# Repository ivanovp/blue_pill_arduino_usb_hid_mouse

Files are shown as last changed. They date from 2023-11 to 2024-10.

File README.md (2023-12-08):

# blue_pill_arduino_usb_hid_keyboard
Macro keyboard which uses Blue Pill (STM32F103) development board and Arduino framework.
Pressing a key sends Alt-Windows-F1 (or any combination you want) through USB to the host. The software is very simple: 
to change the key, you need to compile and re-program the device.
There is 3D printed case and 3D printed keycaps for the keyboard, but you can create your own case of course.

Schematic:
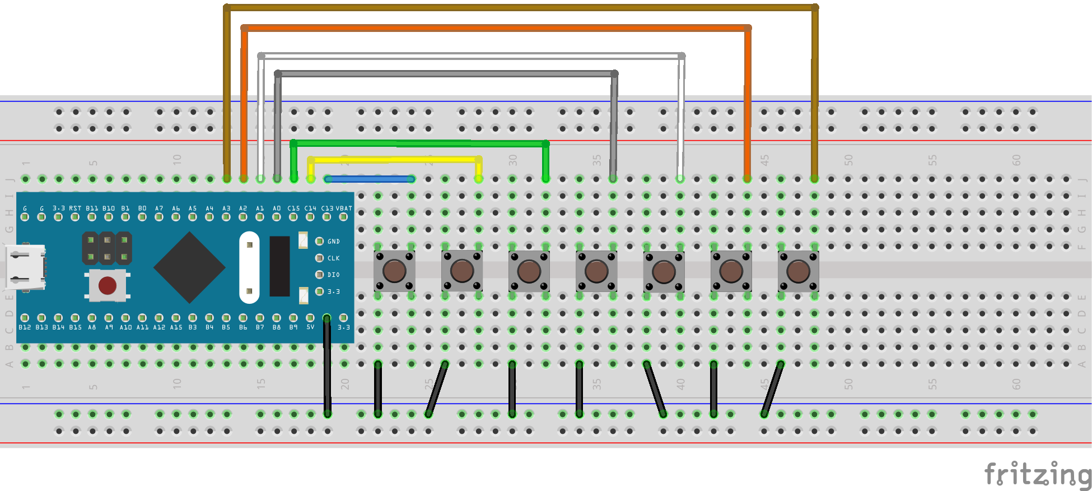
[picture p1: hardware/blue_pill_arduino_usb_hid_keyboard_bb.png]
Schematic


Photos:
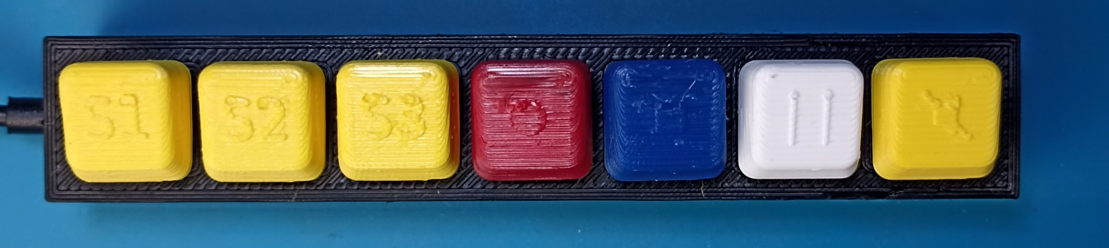
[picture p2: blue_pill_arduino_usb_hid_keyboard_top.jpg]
Macro keyboard top

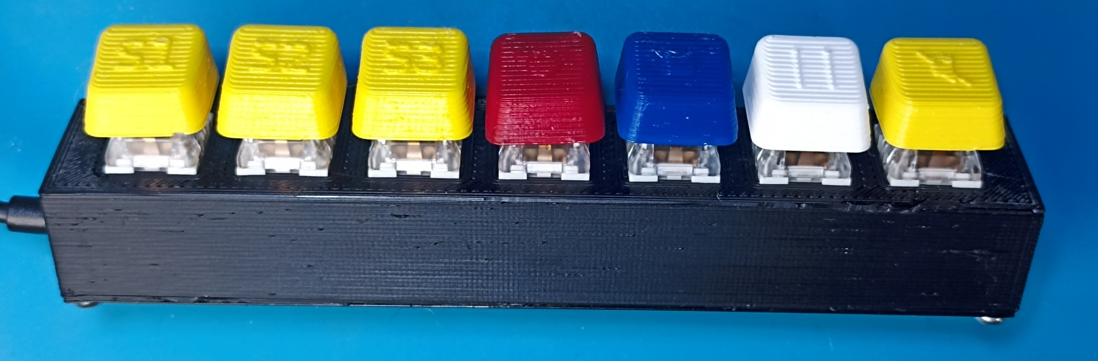
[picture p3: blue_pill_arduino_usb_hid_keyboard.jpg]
Macro keyboard


Bill of Materials:

Blue Pill (STM32F103C8, 64KiB flash):
https://www.hestore.hu/prod_10043289.html

Blue Pill (STM32F103C6, 32KiB flash):
https://pepita.hu/muszaki-cikk-elektronika-outlet-c6343/stm32f103c6t6-mikrokontroller-fejleszto-modul-p10464316

ST-Link V2:
https://www.hestore.hu/prod_10037590.html

Mechanical switches:
https://www.alza.hu/keychron-kailh-switch-set-35pcsset-brown-d6587566.htm
https://www.alza.hu/keychron-kailh-switch-set-35pcsset-red-d6587574.htm

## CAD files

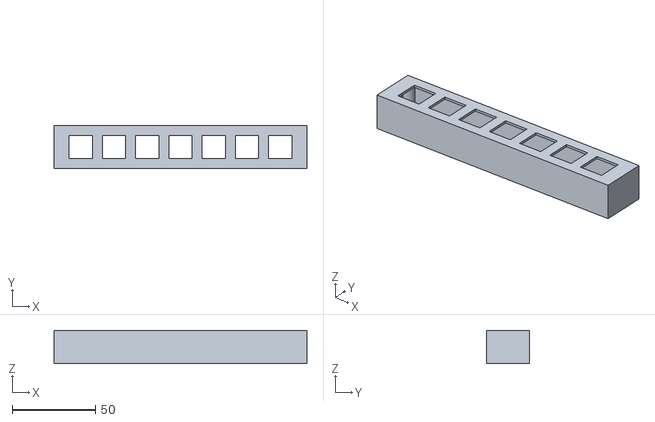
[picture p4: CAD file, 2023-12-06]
3d_printed/case/macro_keyboard_case_top.stl
152.0 x 26.0 x 20.0

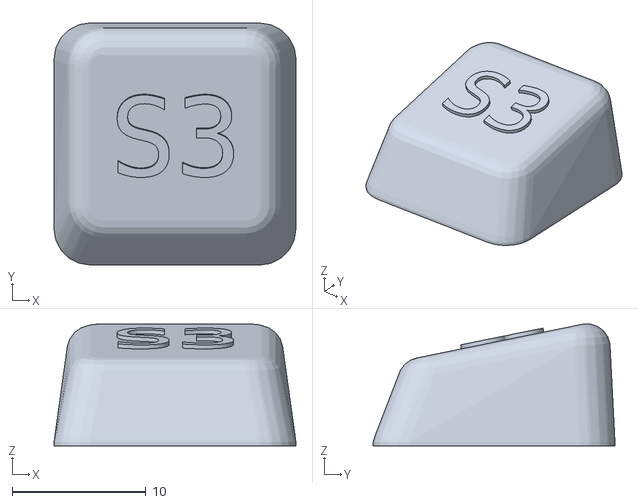
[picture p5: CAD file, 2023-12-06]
3d_printed/keycap_2783650/key_s3.stl
18.1 x 18.1 x 9.12

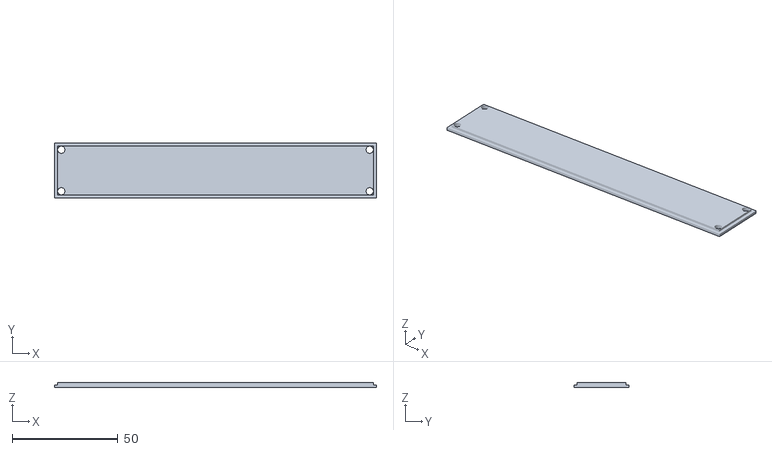
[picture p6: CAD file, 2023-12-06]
3d_printed/case/macro_keyboard_case_bottom.stl
152.0 x 26.0 x 2.40

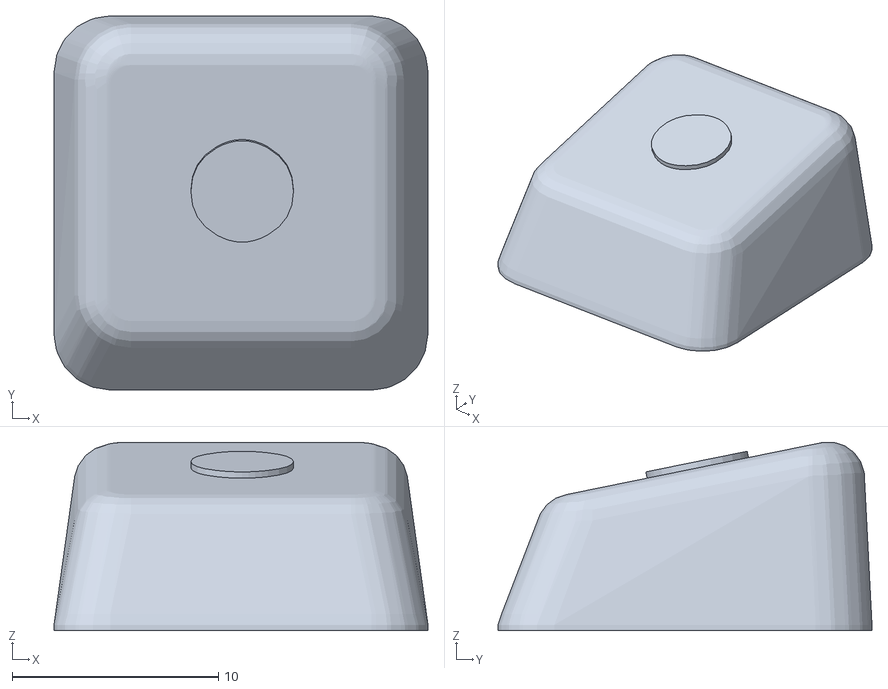
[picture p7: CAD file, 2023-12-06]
3d_printed/keycap_2783650/key_record.stl
18.1 x 18.1 x 9.12

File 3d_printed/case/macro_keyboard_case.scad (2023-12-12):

// Copyright (C) Peter Ivanov <ivanovp@gmail.com>, 2023
// License: Attribution-NonCommercial-ShareAlike (CC BY-NC-SA)

/* 1: Render top of case */
enable_top = 1;
/* 1: Render bottom of case */
enable_bottom = 0;

case_height = 20;
keybody_width = 14;
keybody_length = 14;
keybody_height = 8;
thickness = 1.3;
/* Number of keys in a row */
key_num_per_row = 7;
/* Number of rows */
key_rows = 2;
key_space_x = 6;
key_space_x_left = 3;
key_space_x_right = 3;
key_space_y = 6;
cylinder_outer_diameter = 6.4;
cylinder_inner_diameter = 2.9;
/* 4 drill's diameter to fasten bottom part to the top */
drill_diameter = 3.4;
/* Cutout for USB cable */
cutout_width = 11;
cutout_height = 8;

/* Internal variables */
delta = 0.1;
w = keybody_width + key_space_x;
fw = w * key_num_per_row + key_space_x + key_space_x_left + key_space_x_right;
d = keybody_length * key_rows + key_space_y * (key_rows + 1);
echo("Internal depth: ", d - thickness * 2);
epsilon = 0.1;
$fn = 64;

module cyl()
{
    color("lightblue") difference()
    {
        cylinder(h=case_height - thickness, d=cylinder_outer_diameter);
        translate([0, 0, -epsilon]) cylinder(h=case_height - thickness + epsilon * 2, d=cylinder_inner_diameter);
    }
}

module cyl2()
{
    translate([0, 0, -epsilon]) cylinder(h=case_height - thickness + epsilon * 2, d=drill_diameter);
}

if (enable_top)
{
    translate([cylinder_outer_diameter / 2, cylinder_outer_diameter / 2, thickness]) cyl();
    translate([fw - cylinder_outer_diameter / 2, cylinder_outer_diameter / 2, thickness]) cyl();
    translate([cylinder_outer_diameter / 2, d - cylinder_outer_diameter / 2, thickness]) cyl();
    translate([fw - cylinder_outer_diameter / 2, d - cylinder_outer_diameter / 2, thickness]) cyl();

    color("lightblue") difference()
    {
        cube([fw, d, case_height]);
        translate([thickness, thickness, -epsilon]) cube([fw - thickness * 2, d - thickness * 2, case_height - thickness + epsilon]);
        for (j = [0 : key_rows - 1])
        {
            for (i = [0 : key_num_per_row - 1])
            {
                translate([key_space_x_left + i * w + key_space_x, key_space_y + j * (keybody_length + key_space_y), case_height - keybody_height / 2]) cube([keybody_width, keybody_length, keybody_height]);
            }
        }
        translate([-epsilon, keybody_length / 2 + key_space_y - cutout_width / 2, thickness]) cube([thickness + epsilon * 2, cutout_width, cutout_height]);
    }
}

if (enable_bottom)
{
    translate([0, 0, -thickness]) difference()
    {
        union()
        {
            cube([fw, d, thickness]);
            translate([thickness + delta, thickness + delta, thickness]) cube([fw - thickness * 2 - delta * 2, d - thickness * 2 - delta * 2, thickness - delta * 2]);    
        }
        translate([cylinder_outer_diameter / 2, cylinder_outer_diameter / 2, 0]) cyl2();
        translate([fw - cylinder_outer_diameter / 2, cylinder_outer_diameter / 2, 0]) cyl2();
        translate([cylinder_outer_diameter / 2, d - cylinder_outer_diameter / 2, 0]) cyl2();
        translate([fw - cylinder_outer_diameter / 2, d - cylinder_outer_diameter / 2, 0]) cyl2();       
    }
}

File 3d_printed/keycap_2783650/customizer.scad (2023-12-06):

// entry point for customizer script. This probably isn't useful to most people,
// as it's just a wrapper that helps generate customizer.scad for thingiverse.

/* [Basic-Settings] */

// what preset profile do you wish to use? disable if you are going to set paramters below
key_profile = "g20"; // [dcs, oem, dsa, sa, g20, disable]
// what key profile row is this keycap on? 0 for disable
row = 1; // [5,1,2,3,4,0]

// What does the top of your key say?
legend = "S1";

/* [Basic-Settings] */

// Length in units of key. A regular key is 1 unit; spacebar is usually 6.25
$key_length = 1.0; // Range not working in thingiverse customizer atm [1:0.25:16]

// What type of stem you want. Most people want Cherry.
$stem_type = "cherry";  // [cherry, alps, rounded_cherry, box_cherry, filled, disable]

// The stem is the hardest part to print, so this variable controls how much 'slop' there is in the stem
$stem_slop = 0.3; // Not working in thingiverse customizer atm [0:0.01:1]

// Font size used for text
$font_size = 6;

// Set this to true if you're making a spacebar!
$inverted_dish = false;


// Support type. default is "flared" for easy FDM printing; bars are more realistic, and flat could be for artisans
$support_type = "flared"; // [flared, bars, flat, disable]

// Supports for the stem, as it often comes off during printing. Reccommended for most machines
$stem_support_type = "tines"; // [tines, brim, disabled]

/* [Advanced] */

/* Key */
// Height in units of key. should remain 1 for most uses
$key_height = 1.0;
// Keytop thickness, aka how many millimeters between the inside and outside of the top surface of the key
$keytop_thickness = 1;
// Wall thickness, aka the thickness of the sides of the keycap. note this is the total thickness, aka 3 = 1.5mm walls
$wall_thickness = 3;
// Radius of corners of keycap
$corner_radius = 1;
// Width of the very bottom of the key
$bottom_key_width = 18.16;
// Height (from the front) of the very bottom of the key
$bottom_key_height = 18.16;
// How much less width there is on the top. eg top_key_width = bottom_key_width - width_difference
$width_difference = 6;
// How much less height there is on the top
$height_difference = 4;
// How deep the key is, before adding a dish
$total_depth = 11.5;
// The tilt of the dish in degrees. divided by key height
$top_tilt = -6;
// How skewed towards the back the top is (0 for center)
$top_skew = 1.7;

/* Stem */

// How far the throw distance of the switch is. determines how far the 'cross' in the cherry switch digs into the stem, and how long the keystem needs to be before supports can start. luckily, alps and cherries have a pretty similar throw. can modify to have stouter keycaps for low profile switches, etc
$stem_throw = 4;
// Diameter of the outside of the rounded cherry stem
$rounded_cherry_stem_d = 5.5;


// How much higher the stem is than the bottom of the keycap.
// Inset stem requires support but is more accurate in some profiles
$stem_inset = 0;
// How many degrees to rotate the stems. useful for sideways keycaps, maybe
$stem_rotation = 0;

/* Shape */

// Key shape type, determines the shape of the key. default is 'rounded square'
$key_shape_type = "rounded_square";
// ISO enter needs to be linear extruded NOT from the center. this tells the program how far up 'not from the center' is
$linear_extrude_height_adjustment = 0;
// How many slices will be made, to approximate curves on corners. Leave at 1 if you are not curving corners
// If you're doing fancy bowed keycap sides, this controls how many slices you take
$height_slices = 1;

/* Dish */

// What type of dish the key has. note that unlike stems and supports a dish ALWAYS gets rendered.
$dish_type = "cylindrical"; // [cylindrical, spherical, sideways cylindrical, old spherical, disable]
// How deep the dish 'digs' into the top of the keycap. this is max depth, so you can't find the height from total_depth - dish_depth. besides the top is skewed anyways
$dish_depth = 1;
// How skewed in the x direction the dish is
$dish_skew_x = 0;
// How skewed in the y direction (height) the dish is
$dish_skew_y = 0;
// If you need the dish to extend further, you can 'overdraw' the rectangle it will hit
$dish_overdraw_width = 0;
// Same as width but for height
$dish_overdraw_height = 0;

/* Misc */
// There's a bevel on the cherry stems to aid insertion / guard against first layer squishing making a hard-to-fit stem.
$cherry_bevel = true;

// How tall in mm the stem support is, if there is any. stem support sits around the keystem and helps to secure it while printing.
$stem_support_height = 0.4;
// Font used for text
$font="DejaVu Sans Mono:style=Book";
// Whether or not to render fake keyswitches to check clearances
$clearance_check = false;
// Use linear_extrude instead of hull slices to make the shape of the key
// Should be faster, also required for concave shapes
$linear_extrude_shape = false;
//should the key be rounded? unnecessary for most printers, and very slow
$rounded_key = false;
//minkowski radius. radius of sphere used in minkowski sum for minkowski_key function. 1.75 for G20
$minkowski_radius = .33;

/* Features */

//insert locating bump
$key_bump = false;
//height of the location bump from the top surface of the key
$key_bump_depth = 0.5;
//distance to move the bump from the front edge of the key
$key_bump_edge = 0.4;

/* [Hidden] */

//list of legends to place on a key format: [text, halign, valign, size]
//halign = "left" or "center" or "right"
//valign = "top" or "center" or "bottom"
// Currently does not work with thingiverse customizer, and actually breaks it
$legends = [];

// Dimensions of alps stem
$alps_stem = [4.45, 2.25];

// Enable stabilizers. If you don't want stabilizers use disable; most other keycaps use Cherry stabilizers
$stabilizer_type = "cherry"; // [cherry, rounded_cherry, alps, disable]

// Ternaries are ONLY for customizer. they will NOT work if you're using this in
// OpenSCAD. you should use stabilized(), openSCAD customizer,
// or set $stabilizers directly
// Array of positions of stabilizers
$stabilizers = $key_length >= 6 ? [[-50, 0], [50, 0]] : $key_length >= 2 ? [[-12,0],[12,0]] : [];

// Where the stems are in relation to the center of the keycap, in units. default is one in the center
// Shouldn't work in thingiverse customizer, though it has been...
$stem_positions = [[0,0]];

// key width functions

module u(u=1) {
  $key_length = u;
  children();
}

module 1u() {
  u(1) children();
}

module 1_25u() {
  u(1.25) children();
}

module 1_5u() {
  u(1.5) children();
}

module 2u() {
  u(2) children();
}

module 2_25u() {
  u(2.25) children();
}

module 2_75u() {
  u(2.75) children();
}

module 6_25u() {
  u(6.25) children();
}

// key height functions

module uh(u=1) {
  $key_height = u;
  children();
}

module 1uh() {
  uh(1) children();
}

module 2uh() {
  uh(2) children();
}

module 1_25uh() {
  uh(1.25) children();
}

module 1_5uh() {
  uh(1.5) children();
}

module 2_25uh() {
  uh(2.25) children();
}

module 2_75uh() {
  uh(2.75) children();
}

module 6_25uh() {
  uh(6.25) children();
}
// key profile definitions

// unlike the other files with their own dedicated folders, this one doesn't
// need a selector. I wrote one anyways for customizer support though
module dcs_row(n=3) {
  // names, so I don't go crazy
  $bottom_key_width = 18.16;
  $bottom_key_height = 18.16;
  $width_difference = 6;
  $height_difference = 4;
  $dish_type = "cylindrical";
  $dish_depth = 1;
  $dish_skew_x = 0;
  $dish_skew_y = 0;
  $top_skew = 1.75;

  if (n == 5) {
    $total_depth = 11.5;
    $top_tilt = -6;
    children();
  } else if (n == 1) {
    $total_depth = 8.5;
    $top_tilt = -1;
    children();
  } else if (n == 2) {
    $total_depth = 7.5;
    $top_tilt = 3;
    children();
  } else if (n == 3) {
    $total_depth = 6;
    $top_tilt = 7;
    children();
  } else if (n == 4) {
    $total_depth = 6;
    $top_tilt = 16;
    children();
  } else {
    children();
  }
}
module oem_row(n=3) {
  $bottom_key_width = 18.05;
  $bottom_key_height = 18.05;
  $width_difference = 5.8;
  $height_difference = 4;
  $dish_type = "cylindrical";
  $dish_depth = 1;
  $dish_skew_x = 0;
  $dish_skew_y = 0;
  $top_skew = 1.75;
  $stem_inset = 1.2;
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

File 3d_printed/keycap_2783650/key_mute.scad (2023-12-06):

// entry point for customizer script. This probably isn't useful to most people,
// as it's just a wrapper that helps generate customizer.scad for thingiverse.

/* [Basic-Settings] */

// what preset profile do you wish to use? disable if you are going to set paramters below
key_profile = "g20"; // [dcs, oem, dsa, sa, g20, disable]
// what key profile row is this keycap on? 0 for disable
row = 1; // [5,1,2,3,4,0]

// What does the top of your key say?
// ↻ ◁ || ▷ ↺ 🔇
legend = "🔇";

/* [Basic-Settings] */

// Length in units of key. A regular key is 1 unit; spacebar is usually 6.25
$key_length = 1.0; // Range not working in thingiverse customizer atm [1:0.25:16]

// What type of stem you want. Most people want Cherry.
$stem_type = "cherry";  // [cherry, alps, rounded_cherry, box_cherry, filled, disable]

// The stem is the hardest part to print, so this variable controls how much 'slop' there is in the stem
$stem_slop = 0.3; // Not working in thingiverse customizer atm [0:0.01:1]

// Font size used for text
$font_size = 6;

// Set this to true if you're making a spacebar!
$inverted_dish = false;


// Support type. default is "flared" for easy FDM printing; bars are more realistic, and flat could be for artisans
$support_type = "flared"; // [flared, bars, flat, disable]

// Supports for the stem, as it often comes off during printing. Reccommended for most machines
$stem_support_type = "tines"; // [tines, brim, disabled]

/* [Advanced] */

/* Key */
// Height in units of key. should remain 1 for most uses
$key_height = 1.0;
// Keytop thickness, aka how many millimeters between the inside and outside of the top surface of the key
$keytop_thickness = 1;
// Wall thickness, aka the thickness of the sides of the keycap. note this is the total thickness, aka 3 = 1.5mm walls
$wall_thickness = 3;
// Radius of corners of keycap
$corner_radius = 1;
// Width of the very bottom of the key
$bottom_key_width = 18.16;
// Height (from the front) of the very bottom of the key
$bottom_key_height = 18.16;
// How much less width there is on the top. eg top_key_width = bottom_key_width - width_difference
$width_difference = 6;
// How much less height there is on the top
$height_difference = 4;
// How deep the key is, before adding a dish
$total_depth = 11.5;
// The tilt of the dish in degrees. divided by key height
$top_tilt = -6;
// How skewed towards the back the top is (0 for center)
$top_skew = 1.7;

/* Stem */

// How far the throw distance of the switch is. determines how far the 'cross' in the cherry switch digs into the stem, and how long the keystem needs to be before supports can start. luckily, alps and cherries have a pretty similar throw. can modify to have stouter keycaps for low profile switches, etc
$stem_throw = 4;
// Diameter of the outside of the rounded cherry stem
$rounded_cherry_stem_d = 5.5;


// How much higher the stem is than the bottom of the keycap.
// Inset stem requires support but is more accurate in some profiles
$stem_inset = 0;
// How many degrees to rotate the stems. useful for sideways keycaps, maybe
$stem_rotation = 0;

/* Shape */

// Key shape type, determines the shape of the key. default is 'rounded square'
$key_shape_type = "rounded_square";
// ISO enter needs to be linear extruded NOT from the center. this tells the program how far up 'not from the center' is
$linear_extrude_height_adjustment = 0;
// How many slices will be made, to approximate curves on corners. Leave at 1 if you are not curving corners
// If you're doing fancy bowed keycap sides, this controls how many slices you take
$height_slices = 1;

/* Dish */

// What type of dish the key has. note that unlike stems and supports a dish ALWAYS gets rendered.
$dish_type = "cylindrical"; // [cylindrical, spherical, sideways cylindrical, old spherical, disable]
// How deep the dish 'digs' into the top of the keycap. this is max depth, so you can't find the height from total_depth - dish_depth. besides the top is skewed anyways
$dish_depth = 1;
// How skewed in the x direction the dish is
$dish_skew_x = 0;
// How skewed in the y direction (height) the dish is
$dish_skew_y = 0;
// If you need the dish to extend further, you can 'overdraw' the rectangle it will hit
$dish_overdraw_width = 0;
// Same as width but for height
$dish_overdraw_height = 0;

/* Misc */
// There's a bevel on the cherry stems to aid insertion / guard against first layer squishing making a hard-to-fit stem.
$cherry_bevel = true;

// How tall in mm the stem support is, if there is any. stem support sits around the keystem and helps to secure it while printing.
$stem_support_height = 0.4;
// Font used for text
//$font="DejaVu Sans Mono:style=Book";
$font="Symbola:style=Regular";
//$font="Bitstream Vera Sans";
//$font="Liberation Sans";
// Whether or not to render fake keyswitches to check clearances
$clearance_check = false;
// Use linear_extrude instead of hull slices to make the shape of the key
// Should be faster, also required for concave shapes
$linear_extrude_shape = false;
//should the key be rounded? unnecessary for most printers, and very slow
$rounded_key = false;
//minkowski radius. radius of sphere used in minkowski sum for minkowski_key function. 1.75 for G20
$minkowski_radius = .33;

/* Features */

//insert locating bump
$key_bump = false;
//height of the location bump from the top surface of the key
$key_bump_depth = 0.5;
//distance to move the bump from the front edge of the key
$key_bump_edge = 0.4;

/* [Hidden] */

//list of legends to place on a key format: [text, halign, valign, size]
//halign = "left" or "center" or "right"
//valign = "top" or "center" or "bottom"
// Currently does not work with thingiverse customizer, and actually breaks it
$legends = [];

// Dimensions of alps stem
$alps_stem = [4.45, 2.25];

// Enable stabilizers. If you don't want stabilizers use disable; most other keycaps use Cherry stabilizers
$stabilizer_type = "cherry"; // [cherry, rounded_cherry, alps, disable]

// Ternaries are ONLY for customizer. they will NOT work if you're using this in
// OpenSCAD. you should use stabilized(), openSCAD customizer,
// or set $stabilizers directly
// Array of positions of stabilizers
$stabilizers = $key_length >= 6 ? [[-50, 0], [50, 0]] : $key_length >= 2 ? [[-12,0],[12,0]] : [];

// Where the stems are in relation to the center of the keycap, in units. default is one in the center
// Shouldn't work in thingiverse customizer, though it has been...
$stem_positions = [[0,0]];

// key width functions

module u(u=1) {
  $key_length = u;
  children();
}

module 1u() {
  u(1) children();
}

module 1_25u() {
  u(1.25) children();
}

module 1_5u() {
  u(1.5) children();
}

module 2u() {
  u(2) children();
}

module 2_25u() {
  u(2.25) children();
}

module 2_75u() {
  u(2.75) children();
}

module 6_25u() {
  u(6.25) children();
}

// key height functions

module uh(u=1) {
  $key_height = u;
  children();
}

module 1uh() {
  uh(1) children();
}

module 2uh() {
  uh(2) children();
}

module 1_25uh() {
  uh(1.25) children();
}

module 1_5uh() {
  uh(1.5) children();
}

module 2_25uh() {
  uh(2.25) children();
}

module 2_75uh() {
  uh(2.75) children();
}

module 6_25uh() {
  uh(6.25) children();
}
// key profile definitions

// unlike the other files with their own dedicated folders, this one doesn't
// need a selector. I wrote one anyways for customizer support though
module dcs_row(n=3) {
  // names, so I don't go crazy
  $bottom_key_width = 18.16;
  $bottom_key_height = 18.16;
  $width_difference = 6;
  $height_difference = 4;
  $dish_type = "cylindrical";
  $dish_depth = 1;
  $dish_skew_x = 0;
  $dish_skew_y = 0;
  $top_skew = 1.75;

  if (n == 5) {
    $total_depth = 11.5;
    $top_tilt = -6;
    children();
  } else if (n == 1) {
    $total_depth = 8.5;
    $top_tilt = -1;
    children();
  } else if (n == 2) {
    $total_depth = 7.5;
    $top_tilt = 3;
    children();
  } else if (n == 3) {
    $total_depth = 6;
    $top_tilt = 7;
    children();
  } else if (n == 4) {
    $total_depth = 6;
    $top_tilt = 16;
    children();
  } else {
    children();
  }
}
module oem_row(n=3) {
  $bottom_key_width = 18.05;
  $bottom_key_height = 18.05;
  $width_difference = 5.8;
  $height_difference = 4;
  $dish_type = "cylindrical";
  $dish_depth = 1;
  $dish_skew_x = 0;
  $dish_skew_y = 0;
  $top_skew = 1.75;
  $stem_inset = 1.2;
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

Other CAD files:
3d_printed/keycap_2783650/key_pause.stl
3d_printed/keycap_2783650/key_s1.stl
3d_printed/keycap_2783650/key_mute.stl
3d_printed/keycap_2783650/key_stop.stl
3d_printed/keycap_2783650/key_s2.stl
3d_printed/keycap_2783650/key_play_pause.stl
3d_printed/keycap_2783650/key_pause.scad
3d_printed/keycap_2783650/key_play_pause.scad
3d_printed/keycap_2783650/key_record.scad
3d_printed/keycap_2783650/key_s2.scad
3d_printed/keycap_2783650/key_s3.scad
3d_printed/keycap_2783650/key_stop.scad

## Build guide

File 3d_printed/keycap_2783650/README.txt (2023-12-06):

KeyV2: Parametric Mechanical Keycap Library by rsheldiii on Thingiverse: https://www.thingiverse.com/thing:2783650

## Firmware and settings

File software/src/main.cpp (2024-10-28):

/**
 * @file        main.cpp
 * @brief       Entry point and main program
 * @author      Copyright (C) Peter Ivanov, 2023
 *
 * Created      2023-11-30 11:30:53
 * Last modify: 2023-12-06 19:03:55 ivanovp {Time-stamp}
 * Licence:     GPL
 */

#include <Arduino.h>
#include <Mouse.h>
#include <U8g2lib.h>
#include <Wire.h>

#define ENABLE_SERIAL   0
#define ENABLE_LCD      0

#define LED_PIN     PC13

#define SOFTWARE_DEBOUNCE_TIME_MS   500

#define KEY_NUMBER  7

#define KEY0_PIN    PA3
#define KEY1_PIN    PA2
#define KEY2_PIN    PA1
#define KEY3_PIN    PA0
#define KEY4_PIN    PC15
#define KEY5_PIN    PC14
#define KEY6_PIN    PC13
#define KEY7_PIN    PB4
#define KEY8_PIN    PB5
#define KEY9_PIN    PB6
#define KEY10_PIN   PB7
#define KEY11_PIN   PB8
#define KEY12_PIN   PB9
#define KEY13_PIN

uint32_t mouse_press_end_ms = 0;
// uint32_t mouse_press_time_ms = 10 * 1000;
uint32_t mouse_press_time_ms = 60 * 1000;
#if ENABLE_LCD
U8G2_SSD1306_128X32_UNIVISION_F_HW_I2C u8g(U8G2_R0);
#endif

void setLed(bool on=true)
{
    if (!on) /* Reversed logic! */
    {
        digitalWrite(LED_PIN, HIGH);
    }
    else
    {
        digitalWrite(LED_PIN, LOW);
    }
}

void setup()
{
    pinMode(LED_PIN, OUTPUT);
    setLed(false);
    pinMode(KEY0_PIN, INPUT_PULLUP);
#if KEY_NUMBER > 1
    pinMode(KEY1_PIN, INPUT_PULLUP);
#endif
#if KEY_NUMBER > 2
    pinMode(KEY2_PIN, INPUT_PULLUP);
#endif
#if KEY_NUMBER > 3
    pinMode(KEY3_PIN, INPUT_PULLUP);
#endif
#if KEY_NUMBER > 4
    pinMode(KEY4_PIN, INPUT_PULLUP);
#endif
#if KEY_NUMBER > 5
    pinMode(KEY5_PIN, INPUT_PULLUP);
#endif
#if KEY_NUMBER > 6
    pinMode(KEY6_PIN, INPUT_PULLUP);
#endif
#if KEY_NUMBER > 7
    pinMode(KEY7_PIN, INPUT_PULLUP);
#endif
#if KEY_NUMBER > 8
    pinMode(KEY8_PIN, INPUT_PULLUP);
#endif
#if KEY_NUMBER > 9
    pinMode(KEY9_PIN, INPUT_PULLUP);
#endif
#if KEY_NUMBER > 10
    pinMode(KEY10_PIN, INPUT_PULLUP);
#endif
#if KEY_NUMBER > 11
    pinMode(KEY11_PIN, INPUT_PULLUP);
#endif
#if KEY_NUMBER > 12
    pinMode(KEY12_PIN, INPUT_PULLUP);
#endif
#if KEY_NUMBER > 13
    pinMode(KEY13_PIN, INPUT_PULLUP);
#endif
#if ENABLE_SERIAL
    Serial.begin(115200);
    Serial.print("\n\n\n");
    Serial.print("Blue Pill USB HID Keyboard started\n");
    Serial.print("Compiled on " __DATE__ " " __TIME__ "\n");
#endif
    Mouse.begin();
#if ENABLE_LCD
    Wire.begin();
    int r = u8g.begin();
#if ENABLE_SERIAL
    Serial.print("Display init: ");
    Serial.println(r);
#endif
    u8g.setFont(u8g_font_unifont);
#endif
}

void update_display()
{
#if ENABLE_LCD
    static uint32_t last_update_ms = 0;

    if (last_update_ms == 0 || last_update_ms + 500 <= millis())
    {
        last_update_ms = millis();
        u8g.setCursor(0, 0);
        if (Mouse.isPressed(MOUSE_LEFT))
        {
            u8g.print("B1");
        }
        else
        {
            u8g.print("  ");
        }

        u8g.setCursor(0, 22);
        if (mouse_press_end_ms)
        {
            u8g.print("RT: ");
            u8g.print((mouse_press_end_ms - millis()) / 1000);
            u8g.print(" s ");
        }
        else
        {
            u8g.print("RT: -      ");
        }
        u8g.sendBuffer();
    }
#endif
}

void loop()
{
    update_display();
    if (mouse_press_end_ms)
    {
        uint32_t m = millis();
        if (m > mouse_press_end_ms)
        {
#if ENABLE_SERIAL
            Serial.print("Press end due to timout\n");
#endif
            Mouse.release(MOUSE_LEFT);
            mouse_press_end_ms = 0;
        }
        if (((m + 1) % 1000) == 0)
        {
            if (random(0, 99) == 0)
            {
                if (random(0, 1) == 0)
                {
                    Mouse.move(random(-5, 5), 0);
                }
                else
                {
                    Mouse.move(0, random(-5, 5));
                }
            }
        }
    }
    if (digitalRead(KEY0_PIN) == LOW)
    {
#if ENABLE_SERIAL
        Serial.print("Key0 pressed\n");
#endif
        setLed(true);
        if (mouse_press_end_ms)
        {
#if ENABLE_SERIAL
            Serial.print("Increasing time\n");
#endif
            mouse_press_end_ms += mouse_press_time_ms;
        }
        else
        {
#if ENABLE_SERIAL
            Serial.print("Press start\n");
#endif
            Mouse.press(MOUSE_LEFT);
            mouse_press_end_ms = millis() + mouse_press_time_ms;
        }
        delay(SOFTWARE_DEBOUNCE_TIME_MS);
        /* Wait until releasing key */
        while (digitalRead(KEY0_PIN) == LOW);
        setLed(false);
    }
#if KEY_NUMBER > 1
    if (digitalRead(KEY1_PIN) == LOW)
    {
#if ENABLE_SERIAL
        Serial.print("Key1 pressed\n");
#endif
        if (mouse_press_end_ms)
        {
#if ENABLE_SERIAL
            Serial.print("Press end\n");
#endif
            Mouse.release(MOUSE_LEFT);
            mouse_press_end_ms = 0;
        }
        delay(SOFTWARE_DEBOUNCE_TIME_MS);
        /* Wait until releasing key */
        while (digitalRead(KEY1_PIN) == LOW);
    }
#endif
#if KEY_NUMBER > 2
    if (digitalRead(KEY2_PIN) == LOW)
    {
#if ENABLE_SERIAL
        Serial.print("Key2 pressed\n");
#endif
        delay(SOFTWARE_DEBOUNCE_TIME_MS);
        /* Wait until releasing key */
        while (digitalRead(KEY2_PIN) == LOW);
    }
#endif
#if KEY_NUMBER > 3
    if (digitalRead(KEY3_PIN) == LOW)
    {
#if ENABLE_SERIAL
        Serial.print("Key3 pressed\n");
#endif
        delay(SOFTWARE_DEBOUNCE_TIME_MS);
        /* Wait until releasing key */
        while (digitalRead(KEY3_PIN) == LOW);
    }
#endif
#if KEY_NUMBER > 4
    if (digitalRead(KEY4_PIN) == LOW)
    {
#if ENABLE_SERIAL
        Serial.print("Key4 pressed\n");
#endif
        delay(SOFTWARE_DEBOUNCE_TIME_MS);
        /* Wait until releasing key */
        while (digitalRead(KEY4_PIN) == LOW);
    }
#endif
#if KEY_NUMBER > 5
    if (digitalRead(KEY5_PIN) == LOW)
    {
#if ENABLE_SERIAL
        Serial.print("Key5 pressed\n");
#endif
        delay(SOFTWARE_DEBOUNCE_TIME_MS);
        /* Wait until releasing key */
        while (digitalRead(KEY5_PIN) == LOW);
    }
#endif
#if KEY_NUMBER > 6
    if (digitalRead(KEY6_PIN) == LOW)
    {
#if ENABLE_SERIAL
        Serial.print("Key6 pressed\n");
#endif
        delay(SOFTWARE_DEBOUNCE_TIME_MS);
        /* Wait until releasing key */
        while (digitalRead(KEY6_PIN) == LOW);
    }
#endif
#if KEY_NUMBER > 7
    if (digitalRead(KEY7_PIN) == LOW)
    {
#if ENABLE_SERIAL
        Serial.print("Key7 pressed\n");
#endif
        delay(SOFTWARE_DEBOUNCE_TIME_MS);
        /* Wait until releasing key */
        while (digitalRead(KEY7_PIN) == LOW);
    }
#endif
#if KEY_NUMBER > 8
    if (digitalRead(KEY8_PIN) == LOW)
    {
#if ENABLE_SERIAL
        Serial.print("Key8 pressed\n");
#endif
        delay(SOFTWARE_DEBOUNCE_TIME_MS);
        /* Wait until releasing key */
        while (digitalRead(KEY8_PIN) == LOW);
    }
#endif
#if KEY_NUMBER > 9
    if (digitalRead(KEY9_PIN) == LOW)
    {
#if ENABLE_SERIAL
        Serial.print("Key9 pressed\n");
#endif
        delay(SOFTWARE_DEBOUNCE_TIME_MS);
        /* Wait until releasing key */
        while (digitalRead(KEY9_PIN) == LOW);
    }
#endif
#if KEY_NUMBER > 10
    if (digitalRead(KEY10_PIN) == LOW)
    {
#if ENABLE_SERIAL
        Serial.print("Key10 pressed\n");
#endif
        delay(SOFTWARE_DEBOUNCE_TIME_MS);
        /* Wait until releasing key */
        while (digitalRead(KEY10_PIN) == LOW);
    }
#endif
#if KEY_NUMBER > 11
    if (digitalRead(KEY11_PIN) == LOW)
    {
#if ENABLE_SERIAL
        Serial.print("Key11 pressed\n");
#endif
        delay(SOFTWARE_DEBOUNCE_TIME_MS);
        /* Wait until releasing key */
        while (digitalRead(KEY11_PIN) == LOW);
    }
#endif
#if KEY_NUMBER > 12
    if (digitalRead(KEY12_PIN) == LOW)
    {
#if ENABLE_SERIAL
        Serial.print("Key12 pressed\n");
#endif
        delay(SOFTWARE_DEBOUNCE_TIME_MS);
        /* Wait until releasing key */
        while (digitalRead(KEY12_PIN) == LOW);
    }
#endif
#if KEY_NUMBER > 13
    if (digitalRead(KEY13_PIN) == LOW)
    {
#if ENABLE_SERIAL
        Serial.print("Key13 pressed\n");
#endif
        delay(SOFTWARE_DEBOUNCE_TIME_MS);

        /* Wait until releasing key */
        while (digitalRead(KEY13_PIN) == LOW);
    }
#endif
}

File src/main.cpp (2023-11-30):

#include <Arduino.h>
#include <Keyboard.h>

#define LED_PIN     PC13
#define KEY0_PIN    PB11
#define KEY1_PIN    PB10
#define KEY2_PIN    PB1
#define KEY3_PIN    PB0
#define KEY4_PIN    A7
#define KEY5_PIN    A6
#define KEY6_PIN    A5

void setup()
{
    pinMode(LED_PIN, OUTPUT);
    digitalWrite(LED_PIN, LOW);
    pinMode(KEY0_PIN, INPUT_PULLUP);
    pinMode(KEY1_PIN, INPUT_PULLUP);
    pinMode(KEY2_PIN, INPUT_PULLUP);
    pinMode(KEY3_PIN, INPUT_PULLUP);
    pinMode(KEY4_PIN, INPUT_PULLUP);
    pinMode(KEY5_PIN, INPUT_PULLUP);
    pinMode(KEY6_PIN, INPUT_PULLUP);
    Serial.begin(115200);
    Serial.printf("\n\n\n");
    Serial.printf("Blue Pill USB HID Keyboard started\n");
    Serial.printf("Compiled on " __DATE__ " " __TIME__ "\n");
    Keyboard.begin();
}

void loop()
{
    if (digitalRead(KEY0_PIN) == LOW)
    {
        Serial.printf("Key0 pressed\n");
        Keyboard.press(KEY_LEFT_ALT);
        delay(100);
        Keyboard.press(KEY_LEFT_GUI);
        delay(100);
        Keyboard.press(KEY_F1);
        delay(100);
        Keyboard.releaseAll();
        /* Wait until releasing key */
        while (digitalRead(KEY0_PIN) == LOW);
    }
    if (digitalRead(KEY1_PIN) == LOW)
    {
        Serial.printf("Key1 pressed\n");
        Keyboard.press(KEY_LEFT_ALT);
        delay(100);
        Keyboard.press(KEY_LEFT_GUI);
        delay(100);
        Keyboard.press(KEY_F2);
        delay(100);
        Keyboard.releaseAll();
        /* Wait until releasing key */
        while (digitalRead(KEY1_PIN) == LOW);
    }
    if (digitalRead(KEY2_PIN) == LOW)
    {
        Serial.printf("Key2 pressed\n");
        Keyboard.press(KEY_LEFT_ALT);
        delay(100);
        Keyboard.press(KEY_LEFT_GUI);
        delay(100);
        Keyboard.press(KEY_F3);
        delay(100);
        Keyboard.releaseAll();
        /* Wait until releasing key */
        while (digitalRead(KEY2_PIN) == LOW);
    }
    if (digitalRead(KEY3_PIN) == LOW)
    {
        Serial.printf("Key3 pressed\n");
        Keyboard.press(KEY_LEFT_ALT);
        delay(100);
        Keyboard.press(KEY_LEFT_GUI);
        delay(100);
        Keyboard.press(KEY_F4);
        delay(100);
        Keyboard.releaseAll();
        /* Wait until releasing key */
        while (digitalRead(KEY3_PIN) == LOW);
    }
    if (digitalRead(KEY4_PIN) == LOW)
    {
        Serial.printf("Key4 pressed\n");
        Keyboard.press(KEY_LEFT_ALT);
        delay(100);
        Keyboard.press(KEY_LEFT_GUI);
        delay(100);
        Keyboard.press(KEY_F5);
        delay(100);
        Keyboard.releaseAll();
        /* Wait until releasing key */
        while (digitalRead(KEY4_PIN) == LOW);
    }
    if (digitalRead(KEY5_PIN) == LOW)
    {
        Serial.printf("Key5 pressed\n");
        Keyboard.press(KEY_LEFT_ALT);
        delay(100);
        Keyboard.press(KEY_LEFT_GUI);
        delay(100);
        Keyboard.press(KEY_F6);
        delay(100);
        Keyboard.releaseAll();
        /* Wait until releasing key */
        while (digitalRead(KEY5_PIN) == LOW);
    }
    if (digitalRead(KEY6_PIN) == LOW)
    {
        Serial.printf("Key6 pressed\n");
        Keyboard.press(KEY_LEFT_ALT);
        delay(100);
        Keyboard.press(KEY_LEFT_GUI);
        delay(100);
        Keyboard.press(KEY_F7);
        delay(100);
        Keyboard.releaseAll();
        /* Wait until releasing key */
        while (digitalRead(KEY6_PIN) == LOW);
    }
}

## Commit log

2023-12-06 Configuration for STM32F103C6 was added.
2023-12-06 3D printed keycaps were added.
    [customizer.scad, key_mute.scad, key_mute.stl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]
2023-12-06 3D printed case was added.
    [macro_keyboard_case.scad, macro_keyboard_case_bottom.stl, macro_keyboard_case_top.stl]
2023-12-06 Schematic was added.
    [blue_pill_arduino_usb_hid_keyboard.fzz]
2023-12-08 Bill of Materials was added to readme.
2023-12-11 Gui-Alt-F4 is skipped because Windows detects as Alt-F4 and closes active window.
    [main.cpp]
2023-12-11 Serial prints were disabled. LED was also disabled as Key6 also uses PC13.
2023-12-12 3D printed case was improved: keys can be put in multiple rows.
    [macro_keyboard_case.scad]
2024-10-25 Converted to USB HID mouse device.

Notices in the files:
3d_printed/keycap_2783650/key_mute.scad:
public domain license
